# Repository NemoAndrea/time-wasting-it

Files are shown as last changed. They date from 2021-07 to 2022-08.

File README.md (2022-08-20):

# *Time, wasting it* — a simple raspberry pi powered light clock

'Time, wasting-it' is a simple, raspberry pi-powered clock that uses **lights** instead of hands or digits to convey the time. At random points in time (configurable), the clock will show a playful light pattern. The demonstration and original build uses incandescent lights, but other types of lights can be used without modification.

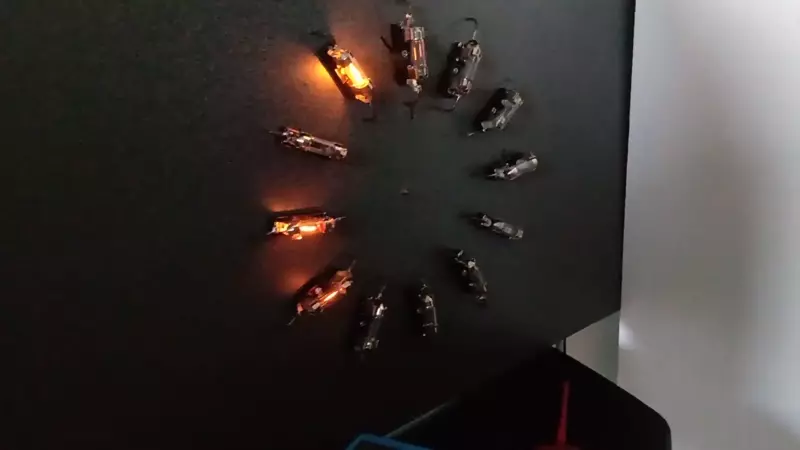
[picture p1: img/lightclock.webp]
lightclock


> The project is a reimaging of the original artwork "*Time, wasting it...*" by **Bo Andrea**. The rebuilt version uses modern hardware to capture the original functionality, which was encoded by much lower level components. The main features (time to light method) and animations (random light patterns at random intervals) are carried over from this original art concept. The original description of the artwork was (in Dutch):
>
> "Koperdraad, buisgloeilampen, microprocessor. Meestal wordt slaafs de tijd aangegeven, zo nu en dan echter..."

The light clock synchronises with internet time, and hence will automatically adjust to winter and summer time. The clock runs a web interface that can be accessed via SSH and exposes manual controls to the user. A different time can be set, some of the config options can be seen at a glance, and an animation can be played back. The web interface also has a virtual mimic of the current clock lights (intensity/PWM) settings, which is handy for debugging if you are hooking up your own custom lights.

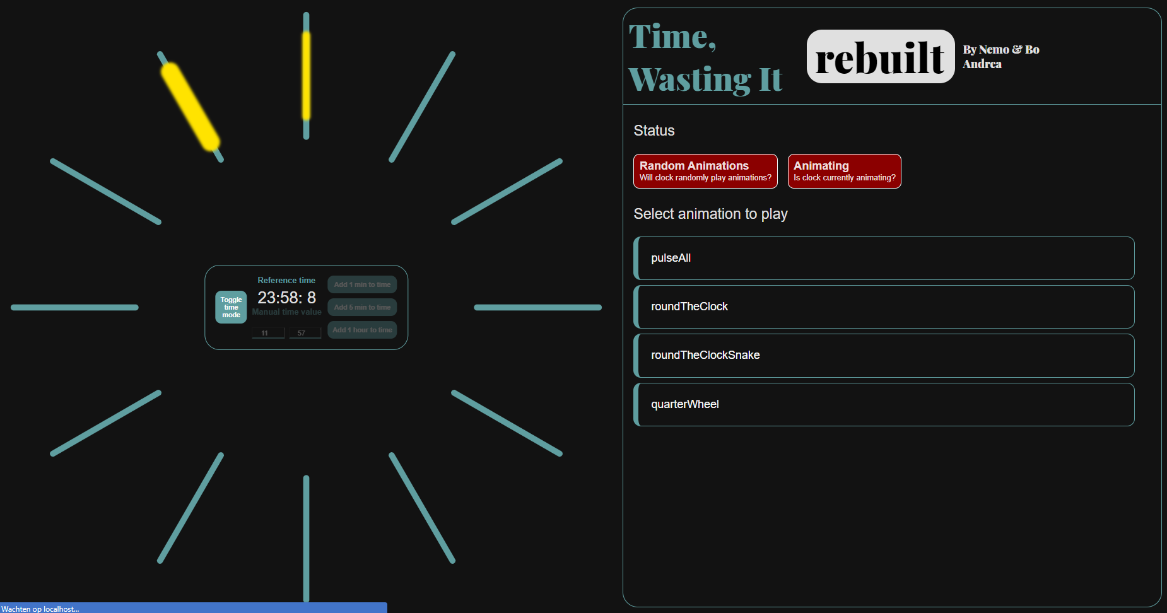
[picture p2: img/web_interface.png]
[web interface screenshot]


### Assembly

Assembling your own clock is not very difficult, provided you have soldering tools, a bit of time, and basic SSH knowledge. 

Briefly, you will need the following components

1. Raspberry pi zero (any variant will do, but a version with wireless connectivity is strongly recommended)
2. The project PCB, which can be ordered online using the `gerber` files in this repository
3. A power supply that has enough power to run your lights of choice
4. A buck converter, if your lights of choice do not run at 5V (the raspberry pi will need 5V)
5. 12 primary lights, that will convey the time. *must be PWM dimmable*
6. Wires, through-hole components and soldering tools

For a more detailed list of the required components and assembly guide, consult [the hardware setup section 📖](./docs/hardware.md)

### Software setup & usage

The software setup for the project (assuming the hardware is assembled and ready)  and configuration starts with the cloning of this repository onto the Raspberry Pi, and then a few simple commands, outlined in greater detail in [the software setup section 📖](./docs/software.md).

> The code is all JavaScript, which at the time was chosen for easy interfacing with the web UI. 

### Project state

The project is complete, and is no longer seeing active development. A running version of the light clock is operational, and has been reliable in use for almost a year (as of time of writing).

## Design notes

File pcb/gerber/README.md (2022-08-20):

# Gerber Files

This directory contains Gerber and drill files which can be directly provided to a PCB manufacturer and with that, an order placed.

If you want to inspect the Gerber files, there are many viewers available. [Kicad](https://www.kicad.org/), which was used to make the designs, comes with a build in `GerbView` utility that can be used to view Gerber files, but you can also use the free [online viewer of Ucamco](https://gerber-viewer.ucamco.com/)

For assembly instructions and more comments on the hardware, consult the [hardware setup section](../../docs/hardware.md)

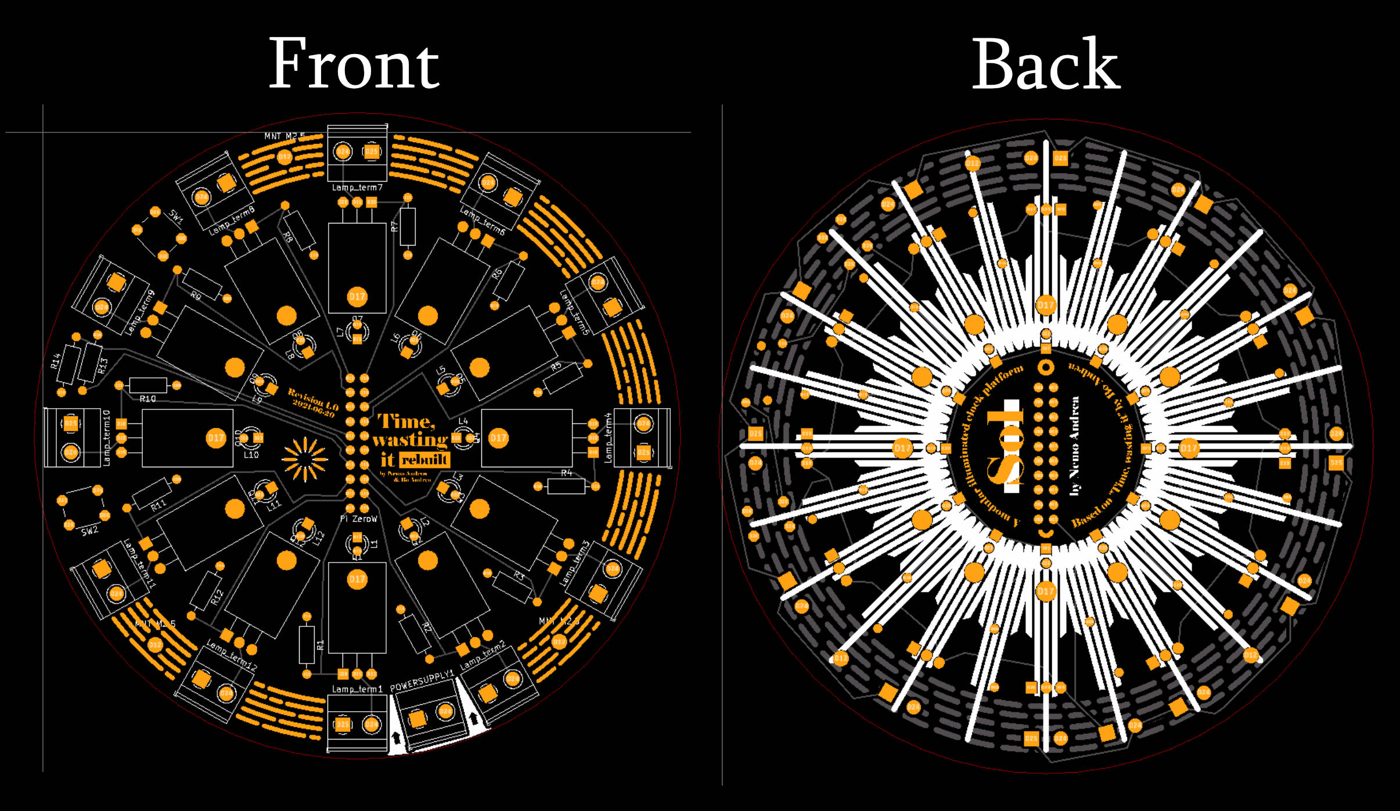
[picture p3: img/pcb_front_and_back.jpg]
pcb_front_and_back


### Produced board

I had my copies of the board make by **JLCPCB**. I think they came out looking quite nice.

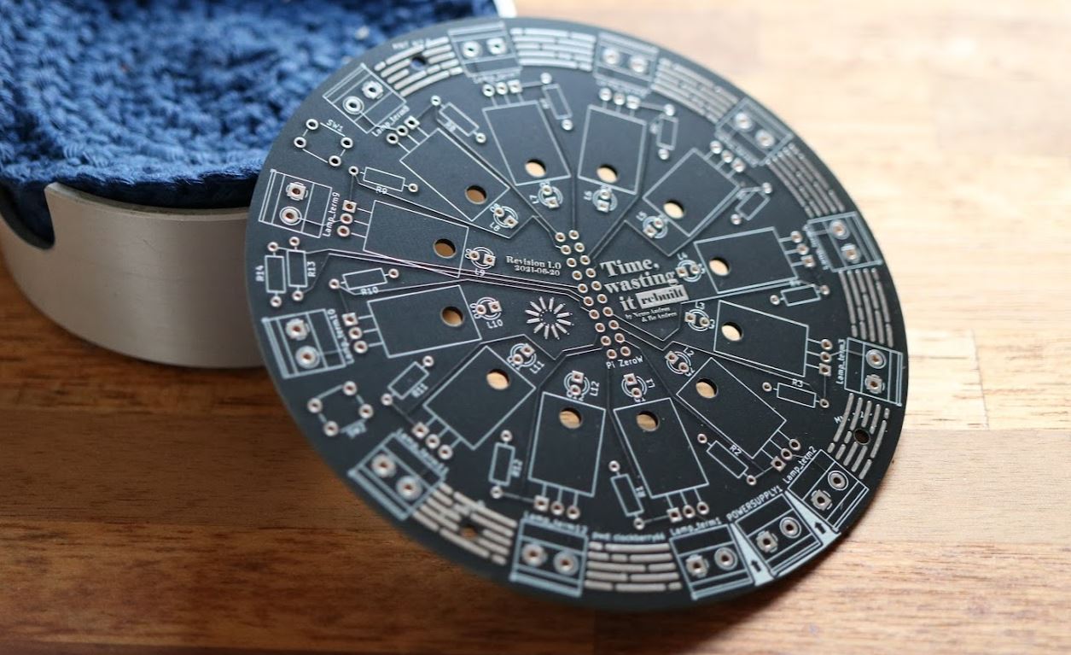
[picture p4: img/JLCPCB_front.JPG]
pcb front


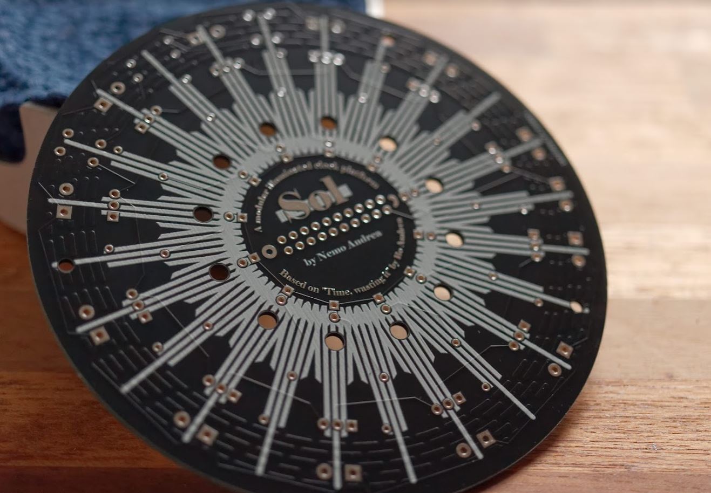
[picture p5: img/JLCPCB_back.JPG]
pcb back


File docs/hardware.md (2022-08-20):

# Hardware setup for *Time, wasting it*

>  ⚠️ **Warning: the PCB design discussed below does not adhere to good design practices and should not be used as reference for how items should be routed or general PCB layout tricks**

### Component list

To build the *time, wasting it* clock, you will need the following components

1. The clock PCB; files can be found [in the PCB folder](../pcb)
2. Wires, solder and soldering station.
3. The following through-hole components
| Item | Ref | amount | price per part in EUR(approximate) |
| --- | --- | --- | --- |
| 3mm Yellow LED (or any led that turns on at 3.3V) | HuiYuan 3004Y1D-EHC-B | 12 | 0.17 |
| IRLZ44N MOSFET | IRLZ44N | 12 | 1 |
| 500 Ohm resistor (52mm) | TC-MOR01SJ0501A10203 | 12 | 0.07 |
| 2-pin terminal block 5.08 pitch | TE Connectivity 796949-2 | 13 | 1.15 |
| 4.3mm button | APEM PHAP3301 | 2 | 0.2 |
| 2x10  header pins for rpi | BKL electronic 393505 | 1 | 0.4 |
| 2x10 header pins (female) for pcb | econ connect MP70D | 1 | 2.6 |
3. A Raspberry Pi Zero W (any revision should work, but tested on Pi Zero W (1))
4. Lights of your choosing (12X). For the build as shown below the [Philips 5552130](https://www.philips.nl/c-p/12866B2/vision-conventionele-binnenverlichting-en-signalering) lamps were used. *About 1 euro per lamp*
5. A power supply. This can be a barrel plug type, or if you have low power consumption lights, you could get away with a USB power supply. For this project I used a `Mean Well GSM60A12-P1J` 12V 5A power supply with standard 5.5mm barrel plug.
   1. You will have to find a way to connect the power supply power and ground to the main terminal on the PCB. This will probably require some extra parts. For this build a barrel plug adapter was used a [generic 5.5mm barrel jack female to terminal adapter](https://www.tinytronics.nl/shop/en/cables-and-connectors/connectors/screw-terminals/dc-jack-female-5.5mm-to-terminal-block)
6. [optional] a PPTC resettable fuse (for the build I used a `ECE RB500-30`)
7. [optional - if your lights do not use a 5V voltage] a buck converter to convert **lamp voltage** to **5V for RPi**. For this build, a generic 12V to 5V buck converter was used.
8. [optional] some kind of 2.5mm mounting solution. The board has three 2.5mm holes that can be used to secure it.

 ### Walkthrough

The PCB is very simple, with the Raspberry Pi GPIO pins driving a MOFSET gate, which then is directly to power supply voltage and the lights. 

> Note that there is **no** in series resistor with the light source, which would be problematic if plain LEDs were used instead of the Philips lamps, which are their own resistor.

There are two extra buttons on the PCB, which are not essential to the clock's functioning, and so can be left out. They can be useful during the testing process. Lights are hooked into screw terminals. For LED light sources, be careful with the polarity.

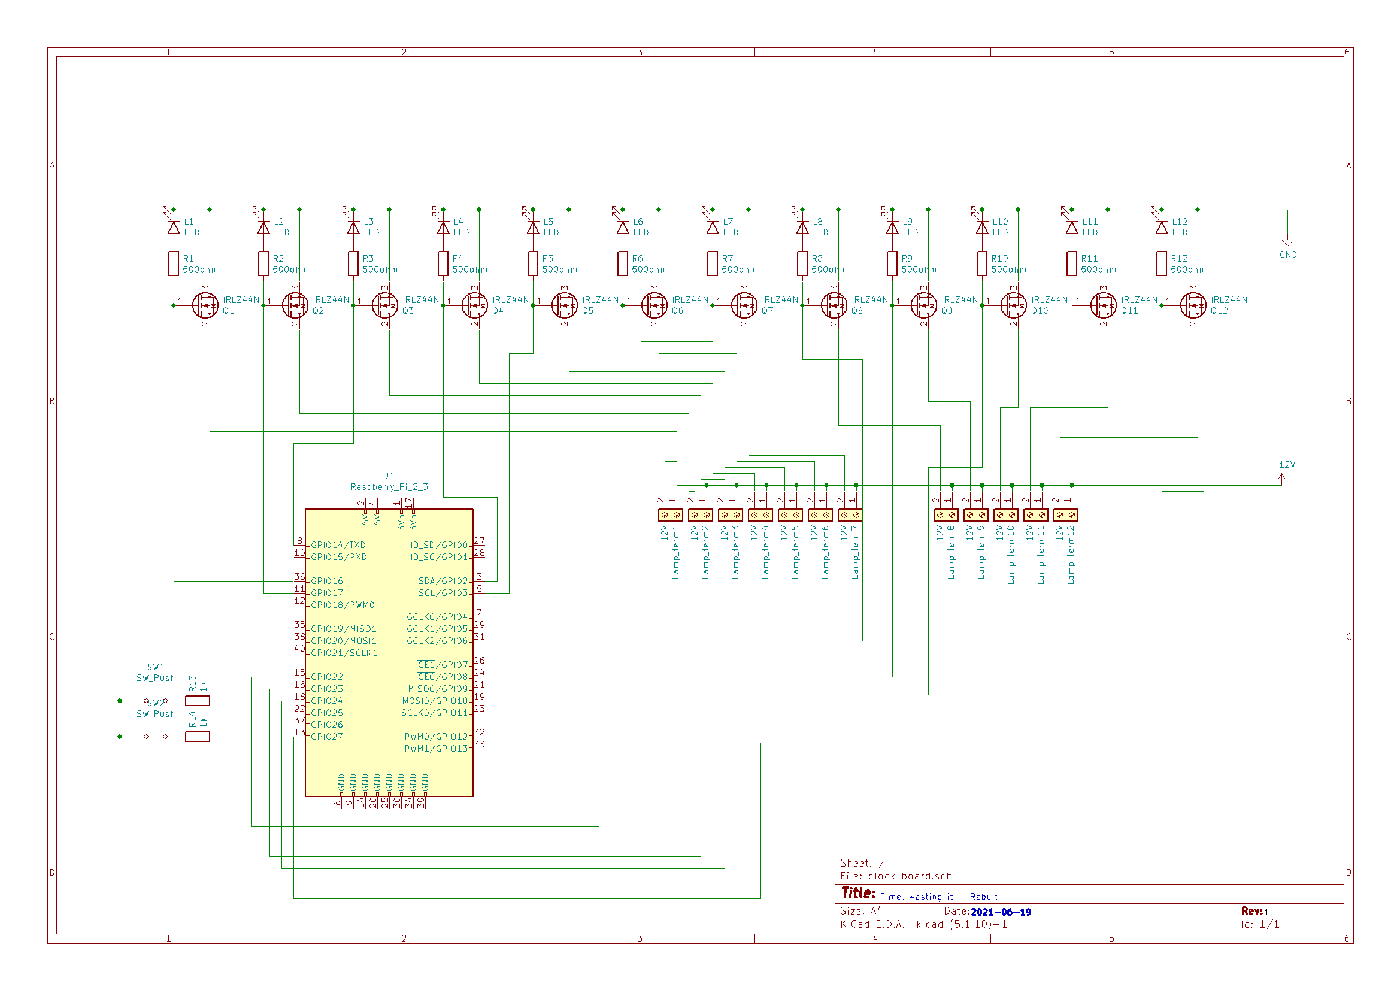
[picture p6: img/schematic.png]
PCB schematic


### PCB

The [custom PCB for the project](../pcb) follows the schematic given above, and contains some decorations. Note that some of the copper traces are exposed for cosmetic purposes only. Gerber art was generated using [the gerbolyze package by jaseg](https://github.com/jaseg/gerbolyze) which makes putting SVG art onto an existing Gerber design easy.

pcb_front_and_back

### Assembly

1. Solder all the through hole components onto the board (MOSFETs, LEDs, terminals, resistors, buttons)

2. Solder the female header pins onto the **back side** of the PCB.

   > It should now look something like this:
   >
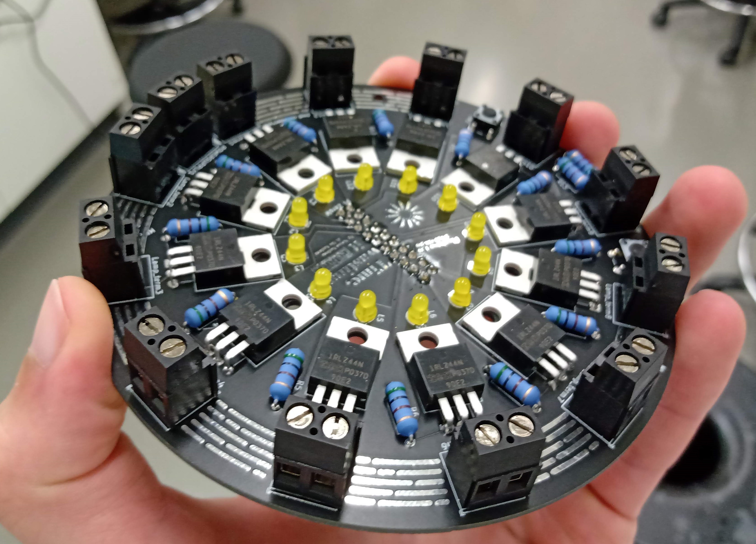
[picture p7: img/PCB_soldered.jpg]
   > 

3. Hook up the lights (whichever type you have chosen) to the 12 terminals

4. Solder the 10x2 header onto the Raspberry Pi zero, making sure to put headers on the exact same places as the image below
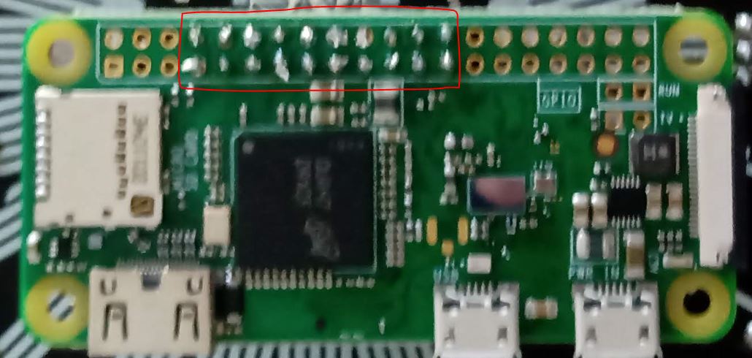
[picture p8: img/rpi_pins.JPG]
raspberry pi header pins
   

5. Add the raspberry to the PCB via the headers. **Note the orientation relative to the PCB art**
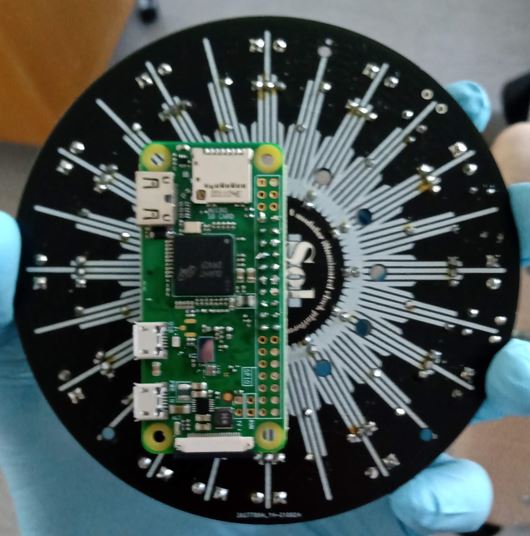
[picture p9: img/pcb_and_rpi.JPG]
raspberry pi and pcb combined
   

6. Make a quick and dirty bypass between these two pins (or better yet, fix it before you order the PCB - source KICAD files are in the directory)
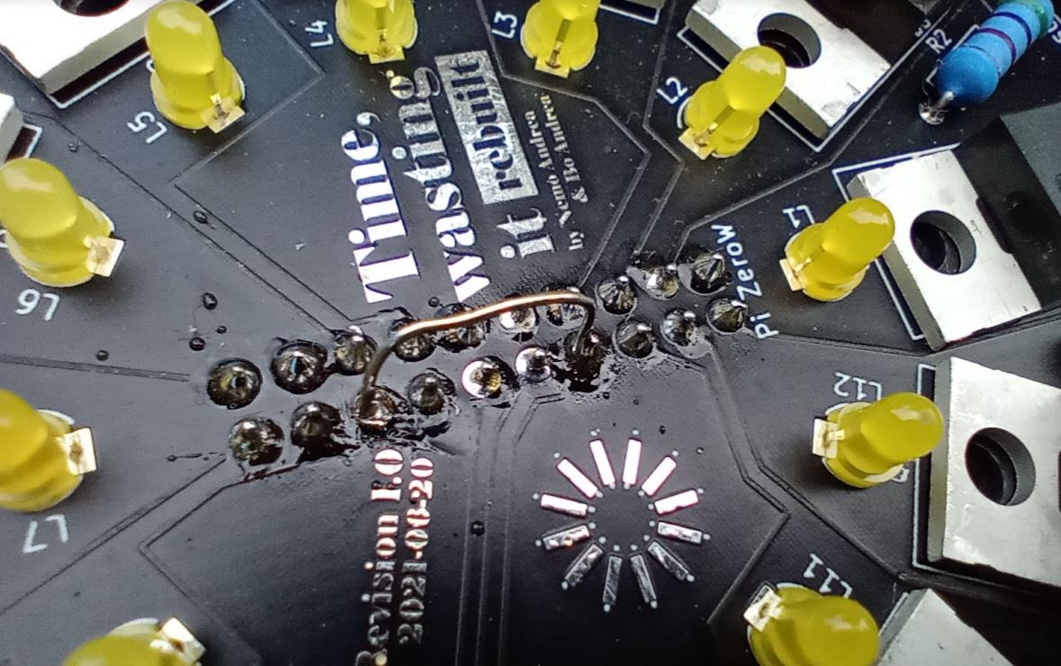
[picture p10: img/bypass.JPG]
   

7. Now we can start to set up the power supply. 

   1. The main PCB gets powered through the 13th terminal. Note the positive (red) and ground (black) locations. This is the voltage that is put on the source of the MOSFETs.
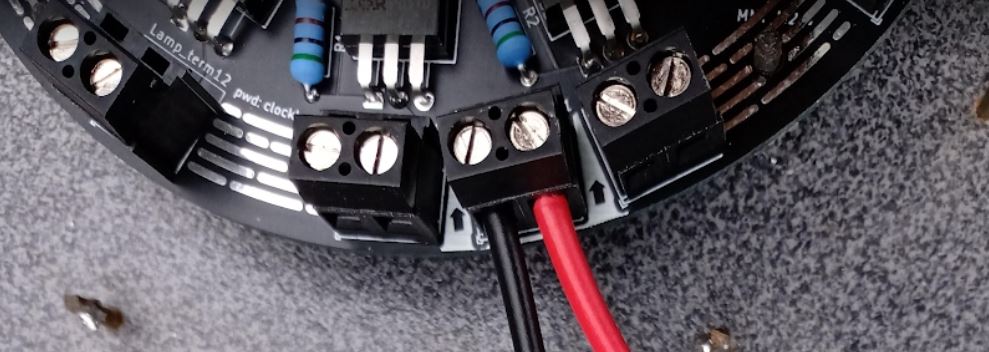
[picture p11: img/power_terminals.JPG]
power supply for pcb
      

   2. The Raspberry Pi will probably need a different voltage than your lights. A simple buck converter can be used for this application. You can either get a buck converter with a USB output, and then power the Raspberry Pi through that usb cable, or solder the +5V and ground directly to the pads on the Raspberry Pi PCB.

      > Note: when soldering directly, be sure to do some research on what are the correct pads. It is easy to get the wrong pad and bypass the fuse of the Pi.
      
   3. [optional] when using a barrel plug for power supply, you can use [this simple 3D-printable part](../3D-printing) that can be used to secure a `5.5mm barrel jack female to terminal adapter` using screws.
   
8. [optional] Add a PPTC fuse (or other kind) to the main power line. That should give some protection against excessive current draw.

### Hardware Issues

There are some issues with the hardware that would best be addressed if you are making your own copy.

1. The PCB trace width is too narrow for the amount of current going through it (for the philips bulbs listed above). The software for the clock offers options to turn down the brightness, but it would be good to make the +12V lines thicker
2. The bypass needed is due to a small error in the routing and interpreting the Raspberry Pi GPIO. A quick edit in KICAD should fix that
3. The power supply listed has a lot of coil whine when drawing large amounts of current. I am not sure what can be done to address that, spare maybe adding a capacitor somewhere. This is probably not a significant issue with lower power draw light sources (and matching power supply).

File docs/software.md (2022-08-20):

# Software setup for *Time, wasting it*

*To run JavaScript code on the Raspberry Pi, we will need to install Node.js. It is slightly nontrivial on a Raspberry Pi, but [if you follow these instructions](https://pimylifeup.com/raspberry-pi-nodejs/) it should be a matter of following along.*

Before anything, make sure this repository is cloned (copied) onto the Raspberry Pi.

### Starting the LightClock

Simply navigate to the repository directory on the raspberry pi, and type

```
sudo node start-clock.js
```

> If you just cloned this repository, you will have to install the dependencies first, by running `node install` in the repository root directory

Alternatively, if you would like to like to automatically start the clock script when the raspberry pi starts, modify `/etc/rc.local` by adding the following two lines (probably best to put them just before the `exit 0` line):

```bash
# some command in rc.local
# another command in rc.local
cd /home/pi/{path-to-lightclock-directory}/
sudo node /home/pi/{path-to-lightclock-directory}/start-clock.js >> /home/pi/{path-to-save-error-logs}/LightClockLog.txt 2>&1
# exit 0
```

Then when you reboot/boot the raspberry pi it will also start the clock. Any errors during boot will be logged to `LightClockLog.txt`.

### Web interface

Running main.js will also run a HTML interface at `localhost:3000` on the raspberry pi. To forward this to your local machine, type (on your local machine):

```
ssh -L <yourlocalhost>:<raspberry_pi_ip>:3000 pi@<raspberry_pi_ip>
```

### Config

You can configure the most common clock settings in `clock-config.json`.

The values settable are:

* `GPIO` : array of integers indicating the GPIO pin numbers as specified in `pigpio`. 

  > If an empty array is provided `[]` the clock will not do any GPIO operations. This is useful if you want to run test's without the hardware and use only the web interface

* `mirroredGPIO`: Boolean value indicating whether to reverse the order of the values in `GPIO`, resulting in the clock pattern being mirrored along the vertical axis. Useful if your hardware layout is mirrored. (e.g. your PCB orientation is backwards w.r.t. the lights of the clock). 

* `GPIObuttons`: array of integers indication GPIO pin numbers to be used for buttons. Used in `PUD_UP` mode. **Only two actions are registered, so the maximum number of GPIO pins that can be entered here is 2.** Leaving it as an empty array  `[]` means no buttons will be used. 

* `PWMlimits` : Object that specifies three limits for PWM values, which in  `pigpio`  can be set between [0,255]

  * `PWMlimits.upper` : maximum PWM value that can be set for GPIO. Safety value and maximum intensity for animations.
  * `PWMlimits.hourHand`: PWM value for the hour hand. Clamped to `PWMlimits.upper`.
  * `PWMlimits.minuteHand`:PWM value for the minute hand. Clamped to `PWMlimits.upper`.

* `timeMode`: String value that either sets the clock to automatic mode (i.e. internet time)  by `"auto"` or to a specific manual time (which will not update with passing time) as `"hh:mm"` or `"hh:mm:ss".`

  > The manual time formats are useful for testing purposes. In normal use there is little reason to change it from `"auto"`

* `randomAnimationFrequency`: a number indicating the mean time (in seconds) it takes for the clock to switch to animation mode. Animation probability is a geometric distribution. Hence the actual time between animation can vary quite a bit 

  > E.g. if you set it to `60` then the mean time at which the animation will play is 60 seconds, but it may well be 40 seconds or 85.

* `webInterface` : options for the html interface that can be used to play with or control the `LightClock`

  * `webInterface.port`: port number to run application at `e.g. localhost:6969`
  * `webInterface.enabled`: Boolean value determining whether to launch the web interface. The web Interface is not required for clock operation, so if you are not testing anything or need direct control over the clock, you could set it to `false`.

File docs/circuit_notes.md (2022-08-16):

# Some notes about the circuit

The sections below are back-of-the-envelope style calculations on the power consumption of the circuit board and give some insight into the design process. I am not an expert by any means on this material, so don't take the approaches below as gospel.

## Resistive lamps

The lamps operate on 12V power.

Power draw (measured, specific to the type of lights used - best if you run your own measurements if you want to be sure):

| PWM value | current draw | power (V*I) |
| --- | --- | --- |
| 30 | 0.14A | 1.68 |
| 60 | 0.24A | 2.9W |
| 100 | 0.36A | 4.3W |
| 200 | 0.6A | 7.2W |
| 255 | 0.72 | 8.6W |

So running 12 lights at max PWM would consume **103 W!** 

Practical values may be at most PWM 60 -> so a total power draw of **34W**, which is more reasonable, and generally not all lights will be on at the same time, so that is fine.

## MOSFETS

The MOSFETs are of type `IRLZ44N`.

Do these need heatsinks for our application?

Let's have a look at the datasheet, provided by Infineon.

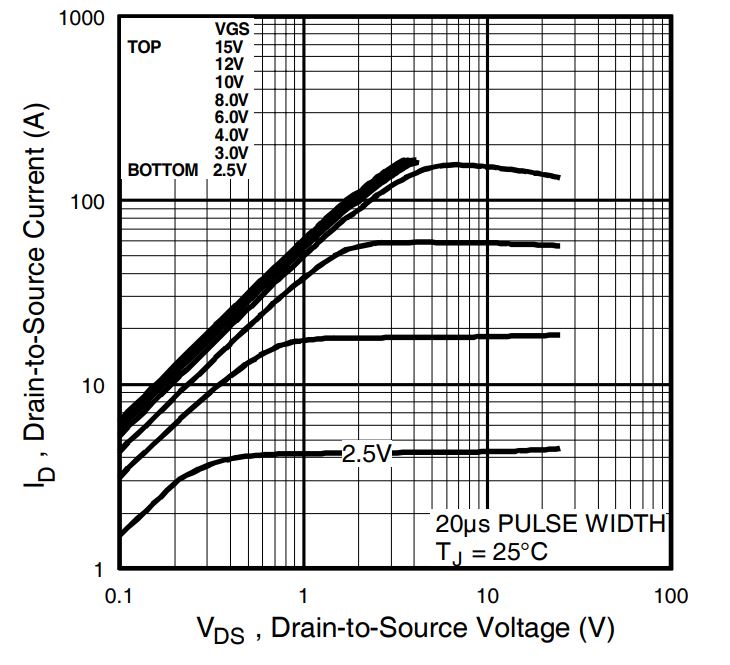
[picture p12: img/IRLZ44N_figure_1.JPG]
IRLZ44N_figure_1


We have a VGS of 3.3 V, so we can look at our maximum current values (0.72A, see above), the V_ds is well under 0.1V. Let's for simplicity call it **0.1V V_ds**.

> Measured V_ds values (when MOSFET gate is high) shows a measured voltage of ~0.05V

The power dissipation in the MOSFET will be **0.1 * 0.72A = 0.07W**. This is **far under 1W**, and hence we do not need any further cooling than the included tiny metal heatsink.

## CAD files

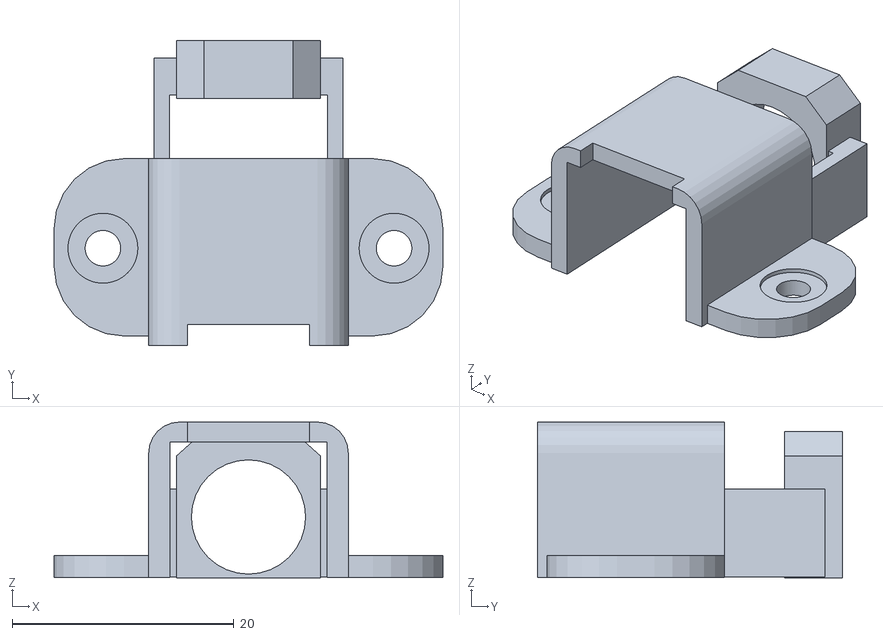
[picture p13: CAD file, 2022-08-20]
3D-printing/barrel_plug_adapter.stl
35.1 x 27.5 x 14.1

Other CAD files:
3D-printing/barrel_plug_adapter.blend

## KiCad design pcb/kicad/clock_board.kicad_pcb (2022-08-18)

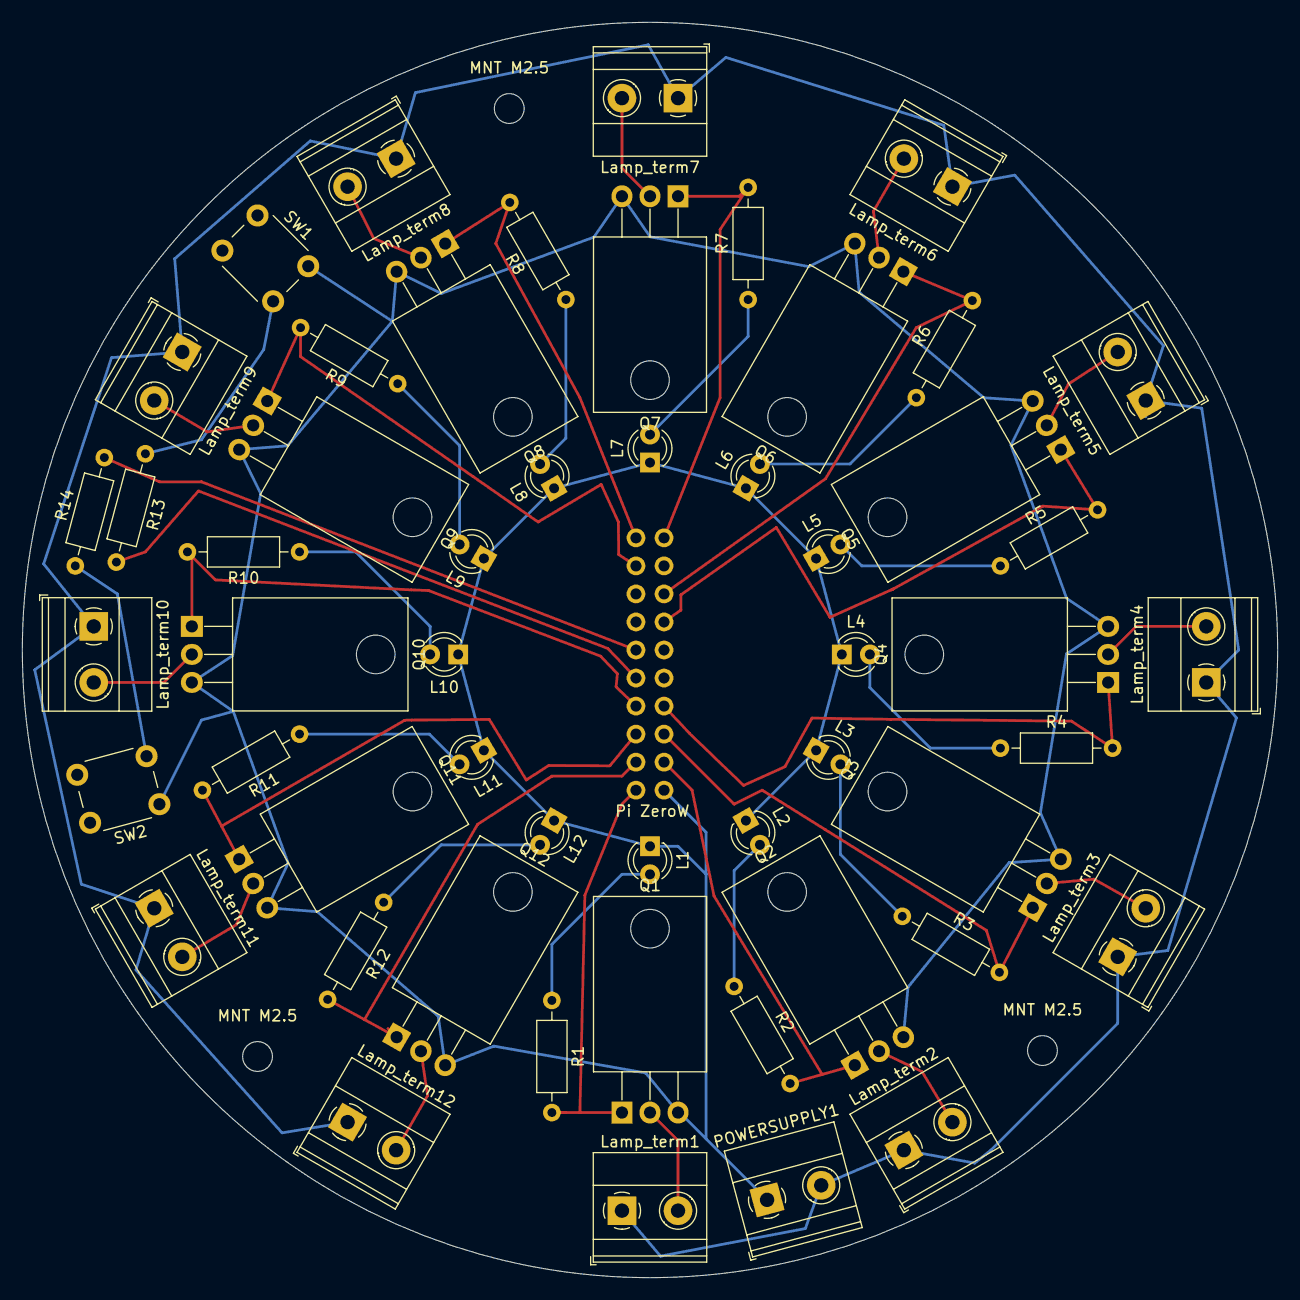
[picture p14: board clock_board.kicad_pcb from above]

Board: 2 copper layers, 113.7 x 113.7 mm, 57 parts (0 on the bottom side), 7 nets.

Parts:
L1, L2, L3, L4, L5, L6, L7, L8, L9, L10, L11, L12: LED; LED_D3.0mm
Lamp_term1, Lamp_term2, Lamp_term3, Lamp_term4, Lamp_term5, Lamp_term6, Lamp_term7, Lamp_term8, Lamp_term9, Lamp_term10, Lamp_term11, Lamp_term12: 12V; TerminalBlock_Phoenix_MKDS-1,5-2-5.08_1x02_P5.08mm_Horizont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
MNT M2.5, MNT M2.5#2, MNT M2.5#3: MountingHole_2.7mm_M2.5
POWERSUPPLY1: 12V; TerminalBlock_Phoenix_MKDS-1,5-2-5.08_1x02_P5.08mm_Horizont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
Pi ZeroW: Raspberry_Pi_Zero_for_clock
Q1, Q2, Q3, Q4, Q5, Q6, Q7, Q8, Q9, Q10, Q11, Q12: IRLZ44N; TO-220-3_Horizontal_TabDown
R1, R2, R3, R4, R5, R6, R7, R8, R9, R10, R11, R12: 500ohm; R_Axial_DIN0207_L6.3mm_D2.5mm_P10.16mm_Horizontal
R13, R14: 1k; R_Axial_DIN0207_L6.3mm_D2.5mm_P10.16mm_Horizontal
SW1, SW2: SW_Push; SW_PUSH_6mm

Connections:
+12V: Lamp_term1.1, Lamp_term2.1, Lamp_term3.1, Lamp_term4.1, Lamp_term5.1, Lamp_term6.1, Lamp_term7.1, Lamp_term8.1, Lamp_term9.1, Lamp_term10.1, Lamp_term11.1, Lamp_term12.1, POWERSUPPLY1.2
GND: L1.1, L2.1, L3.1, L4.1, L5.1, L6.1, L7.1, L8.1, L9.1, L10.1, L11.1, L12.1, POWERSUPPLY1.1, Pi ZeroW.25, Q1.3, Q2.3, Q3.3, Q4.3, Q5.3, Q6.3, Q7.3, Q8.3, Q9.3, Q10.3, Q11.3, Q12.3, SW1.1, SW2.1
unnamed: Q8.1, R8.2
unnamed: L1.2, L2.2, L3.2, L4.2, L5.2, L6.2, L7.2, L8.2, L9.2, L10.2, L11.2, L12.2, R1.1, R2.1, R3.1, R4.1, R5.1, R6.1, R7.1, R8.1, R9.1, R10.1, R11.1, R12.1
unnamed: Lamp_term1.2, Lamp_term2.2, Lamp_term3.2, Lamp_term4.2, Lamp_term5.2, Lamp_term6.2, Lamp_term7.2, Lamp_term8.2, Lamp_term9.2, Lamp_term10.2, Lamp_term11.2, Lamp_term12.2, Q1.2, Q2.2, Q3.2, Q4.2, Q5.2, Q6.2, Q7.2, Q8.2, Q9.2, Q10.2, Q11.2, Q12.2
unnamed: R13.1, SW1.2
unnamed: R14.1, SW2.2

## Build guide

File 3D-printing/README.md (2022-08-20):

# Barrel plug adapter

Simple part to secure a `5.5mm barrel jack female to terminal adapter`. The `.stl` file can be printed, while the `.blend` file (Blender file) contains the source file for the stl object. 

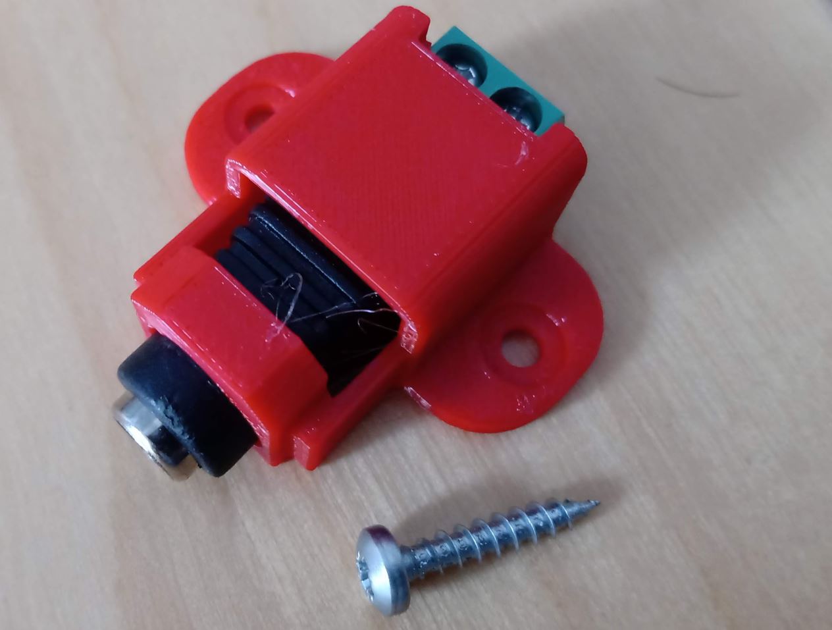
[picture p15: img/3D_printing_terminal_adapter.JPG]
printed terminal adapter


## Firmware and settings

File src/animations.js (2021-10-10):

const range = (start, end, length = end - start + 1) =>
    Array.from({ length }, (_, i) => start + i);

// javascript mod function doesn't handle negative numbers as you may expect. This will fix it
function mod(n, m) {
    return ((n % m) + m) % m;
}

// list of animations (generator functions)
// Add your own by picking a unique name and then follow the general 'Animationframe' and 'yield' formula
// The default tickrate for  the clock is 50, so 300 animation frames is 300/50 = 6 seconds.
let animations = {

    // pulseAll: function* (maxPWM) {
    //     let animationFrame = 0;
    //     let intensity = 0;
    //     let direction = 1;
    //
    //     while (animationFrame < 300) {
    //         animationFrame++;
    //
    //         if (intensity === maxPWM/4) {
    //             direction = -1;
    //         }
    //         if (intensity === 0) {
    //             direction = 1
    //         }
    //         intensity += direction;
    //         let lights = new LightArray(12, intensity);
    //
    //         yield lights
    //     }
    // },

    // roundTheClock: function* () {
    //     let animationFrame = 0;
    //     let intensity = 50;
    //     let lightindex = 0;
    //
    //     while (animationFrame < 200) {
    //         animationFrame++;
    //
    //         let lights =  new LightArray(12);
    //         lightindex = (lightindex + 0.1) % 12;
    //         lights.setValue(lightindex, intensity);
    //
    //         yield lights
    //     }
    // },

    roundTheClockSnake: function* (maxPWM) {
        let animationFrame = 0;
        let intensity = maxPWM;
        let lightindex = 0;

        while (animationFrame < 300) {
            animationFrame++;

            let lights =  new LightArray(12);
            lightindex = (lightindex + 0.2) % 12;
            let floorindex = Math.floor(lightindex);
            lights.setValue(floorindex-3, intensity*1/4);
            lights.setValue(floorindex-2, intensity*2/4);
            lights.setValue(floorindex-1, intensity*3/4);
            lights.setValue(floorindex, intensity);

            yield lights
        }
    },

    roundTheClockSnakeDouble: function* (maxPWM) {
        let animationFrame = 0;
        let intensity = maxPWM;
        let lightindex = 0;

        while (animationFrame < 300) {
            animationFrame++;

            let lights =  new LightArray(12);
            lightindex = mod(lightindex + 0.2, 12);
            let floorindex = Math.floor(lightindex);
            lights.setValue(floorindex-3, intensity*1/4);
            lights.setValue(floorindex-2, intensity*2/4);
            lights.setValue(floorindex-1, intensity*3/4);
            lights.setValue(floorindex, intensity);

            let floorindexTwo = mod(floorindex+6, 12);
            lights.setValue(floorindexTwo-3, intensity*1/4);
            lights.setValue(floorindexTwo-2, intensity*2/4);
            lights.setValue(floorindexTwo-1, intensity*3/4);
            lights.setValue(floorindexTwo, intensity);


            yield lights
        }
    },

    quarterWheel: function* (maxPWM) {
        let animationFrame = 0;
        let intensity = maxPWM;
        let lightindex = 0;

        while (animationFrame <300) {
            animationFrame++;

            let lights = new LightArray(12);
            lightindex = (lightindex + 0.1) % 12;
            lights.setValue(lightindex, intensity);
            lights.setValue((lightindex + 3) % 12,intensity);
            lights.setValue((lightindex + 6) % 12, intensity);
            lights.setValue((lightindex + 9) % 12, intensity);

            yield lights
        }
    },

    // random lights intensities, updated every 10 animation frames
    // randomAll: function* (maxPWM) {
    //     let animationFrame = 0;
    //     let lastLights = new LightArray(12,1);
    //
    //     while (animationFrame < 300) {
    //         animationFrame++;
    //
    //         if (animationFrame % 10 === 0) {
    //             for (let i = 0; i < 12; i++) {
    //                 lastLights.setValue(i, Math.random() * maxPWM / 2)
    //             }
    //         }
    //
    //         yield lastLights
    //     }
    // },

    // random lights intensities (for 6 locations only), updated every 10 animation frames
    randomSix: function* (maxPWM) {
        let animationFrame = 0;
        let lastLights = new LightArray(12);

        while (animationFrame < 300) {
            animationFrame++;

            if (animationFrame % 10 === 0) {
                // clear the old random values
                lastLights =  new LightArray(12);
                // set new random values (only for 6 (or less) random lights)
                for (let i = 0; i < 6; i++) {
                    const lightIndex = Math.floor(Math.random()*12);
                    lastLights.setValue(lightIndex, Math.random() * maxPWM / 2)
                }
            }

            yield lastLights
        }
    },

    // two lights that go around the clock, one faster than the other
    turtleAndHare: function* (maxPWM) {
        let animationFrame = 0;
        let turtle = 0;
        let hare = 0;

        while (animationFrame < 300) {
            animationFrame++;

            let lights = new LightArray(12);

            turtle = (turtle + 0.1) % 12;
            lights.setValue(turtle, maxPWM*3/4);

            hare = (hare + 0.2) % 12;
            lights.setValue(hare, maxPWM*3/4);

            yield lights
        }
    },

    // Sequentially turn on lights and then sequentially turn off lights
    theWave: function* (maxPWM) {
        let animationFrame = 0;
        let mode = 1;
        let lightFront = 0;
        let lastLight = new LightArray(12);

        while (animationFrame < 300) {
            animationFrame++;
            //et lights = new LightArray(12);

            if (lightFront > 12) {
                lightFront = 0;
                mode = mode===1 ? mode = 0 : mode = 1
            }
            lightFront += 0.15;

            lastLight.setValue(lightFront, maxPWM/2 * mode);
            for (const index of range(0, Math.max((lightFront),0))) {
                lastLight.setValue(index, maxPWM/2 * mode);
            }

            yield lastLight
        }
    },

    // 5 neighbouring lights will light up; updated every 20 animation frames
    randomBlock: function* (maxPWM) {
        let animationFrame = 0;
        let lastLights = new LightArray(12);

        while (animationFrame < 300) {
            if (animationFrame % 10 === 0) {
                let blockCenter = Math.floor( Math.random() * 12 );
                lastLights = new LightArray(12); // remove the old block
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

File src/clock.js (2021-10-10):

const Gpio = require('pigpio').Gpio;
const { animationLibrary, LightArray, minuteAnimation } = require('./animations.js');

class LightClock {
    constructor() {
        // default values, (some) to be overriden by config
        this.time = new SimpleTime();
        this.timeMode = 'auto';
        this.animation = null;
        this.randomAnimationFrequency = 0;
        this.animationHistory = {name:'', time: null};
        this.lightArray = new LightArray(12);
        this.PWMlimits = { "upper": 120, "hourHand": 100, "minuteHand": 50};
        this.tickrate = 50;  // clock updates tickrate times per second. Higher is faster.
        this.minuteHand = minuteAnimation(this.tickrate, this.PWMlimits.minuteHand);
        this.nightLimits = [22, 6];  // in hours so 22:00-6:00
        this.nightModeActive=false;
        console.log('LightClock created...');
    }

    start() {  // have the clock start ticking, by repeatedly calling the updateLights() function
        const tickInterval = 1000/this.tickrate;
        setInterval(()=>{
            this.updateLights();
            // }
        }, tickInterval);
    }

    setupGPIO(pins, mirrored=false) {
        console.assert(pins.length > 0, "No pin numbers specified for GPIO (got empty array)");
        let gpio = [];
        // For some applications, you may want to have the lights mirrored along the vertical axis
        // This is simply a matter of reversing the pin order. This is preferred over providing the GPIO pins
        // in reversed order, as this way you can set mirrored=false and get a meaningful output during testing.
        const gpio_pins = mirrored? arrayRotate(pins.reverse(), -1) : pins;
        for (const pin of gpio_pins) {
            gpio.push(new Gpio(pin, {mode: Gpio.OUTPUT}))
        }
        this.gpio_pins = gpio;
        console.log('<< Using GPIO outputs: ', gpio_pins, ' >>');
    }

    setManualTime(timestring) {
        this.timeMode = 'manual';
        // todo validate this
        this.time.fromString(timestring);
    }

    setAutoTime() {
        this.timeMode = 'auto';
        this.time.fromDate()
    }

    startAnimating(animationName=null) {
        if (animationName) { // load specific animation
            if (animationName in animationLibrary) {
                this.animation = {name:animationName, generator:animationLibrary[animationName](this.PWMlimits.upper)};
            } else {
                throw new Error(`requested animation ${animationName} not in animation library.`)
            }
        } else { // select random animation that is NOT the last animation
            let keyoptions = Object.keys(animationLibrary).filter(name => name !== this.animationHistory.name);
            const chosenAnimation = keyoptions[Math.floor(Math.random() * keyoptions.length)];
            this.animation = {name:chosenAnimation, generator:animationLibrary[chosenAnimation](this.PWMlimits.upper)};
            this.animationHistory.name = chosenAnimation;
            console.log('Randomly selected the following animation: ', this.animation.name)
        }
    }

    updateLights() {
        // reset the time array
        this.lightArray = new LightArray(12);

        if (this.animation) { // play animation
            let animation = this.animation.generator.next();
            if (animation.done){
                console.log('ANIMATION FINISHED, BACK TO CLOCK MODE');
                this.animation = null;
            } else {  // animation in progress. set lights.
                this.lightArray = animation.value;
            }
        } else {  // we are not animating, just show the time
            if (this.timeMode === 'auto') { // if we are on auto time, we need to fetch the time first
                this.time.fromDate()
            }
            this.timeToLights();  // convert the SimpleTime to values for the lights

            // check if we should switch to a random animation.
            if (this.randomAnimationFrequency > 0) {
                this.checkAnimation()
            }
        }

        // if we have GPIO output enabled, we should also write LIGHTS to the gpio pins
        if (this.gpio_pins) {
            this.lightsToGpio()
        }
    }

    timeToLights() {
        // set minutes
        this.lightArray.setValue(this.time.getDecimalMinutes() / 5, this.minuteHand.next().value);
        // set hour
        this.lightArray.setValue(this.time.hours, this.PWMlimits.hourHand);
    }

    // write values in this.lightArray to gpio
    lightsToGpio(){
        const oldNightMode = this.nightModeActive;
        const currentHour = new Date().getHours();
        this.nightModeActive = currentHour >= this.nightLimits[0] || currentHour < this.nightLimits[1];
        if (this.nightModeActive !== oldNightMode) { // we switched day/night mode
            if (this.nightModeActive) { console.log("Switching to night mode, dimming the lights...")}
            if (!this.nightModeActive) { console.log("Switching to day mode, lights back to normal brightness!")}
        }

        if (this.nightModeActive) { // we are in NightMode
            // lower (the intensities and the maximum value by 2 (dimmer lights)
            this.gpio_pins.forEach((pin, index) => {
                let brightness = Math.min(Math.round(this.lightArray.lights[index]/2), Math.floor(this.PWMlimits.upper/2));
                pin.pwmWrite(brightness);
            });
        } else { // we are in normal (daytime) mode
            this.gpio_pins.forEach((pin, index) => {
                let brightness = Math.min(this.lightArray.lights[index], this.PWMlimits.upper);
                pin.pwmWrite(brightness);
            });
        }
    }

    // toss a coin and see if we should animate now
    checkAnimation() {
        if (this.randomAnimationFrequency !== 0) {  // if it is zero it would be pointless to compute the next step
            // toss a (biased) coin and see if we should animate based on outcome
            // the randomAnimationFrequency sets the time (s) it takes from the last animation
            // for a 50% chance for the next event. -> geometric distribution E[X]=1/p
            // we know E[x] = this.randomAnimationFrequency * this.tickrate
            const p = 1 / (this.randomAnimationFrequency * this.tickrate);
            if (Math.random() < p) {
                this.startAnimating()
            }
        }
    }
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

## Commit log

2021-07-10 Notes
    Adding some notes about power draw and heating
2021-07-16 First implementation of animations
    Play a rarndom animation from list of animations. Will not play the last played animation again. Animations currently based off frames, rather than time. Added seconds precision to SimpleTime
2021-07-31 Animation & Button update
    Add basic button support for default project PCB. Add more animations. Properly support maxPWM for animations. Minor interface updates to enable longer list of animations. Added option to reverse GPIO array.
    [animations.js, clock.js, start-clock.js]
2022-08-18 Add gerber and kicad source files
    Added the raw gerber files for fab and the kicad source files used for board design.
    [clock_board.kicad_pcb, clock_board.sch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]
2022-08-20 Add hardware assembly instructions and docs
    Added the hardware assembly instructions, some more images, and 3D printable part.
    [barrel_plug_adapter.blend, barrel_plug_adapter.stl]
